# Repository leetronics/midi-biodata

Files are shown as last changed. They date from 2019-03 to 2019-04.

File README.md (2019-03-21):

# MIDI Biodata Sonification system

This repository was originally a fork of https://github.com/electricityforprogress/MIDIsprout, but is now maintained seperately by 13-37.org electronics.

Here you find the hardware and enclosure design files for the MIDI Biodata Sonification Devices produced by 13-37.org electronics.

- enclosures: contains FreeCAD design and STL files for the enclosure
- firmware: 
  - MIDI_Psychogalv_328p_v021: unmodified firmware from electricityforprogress/MIDIsprout
  - MIDI_Psychogalv_328p_13-37.org_v2.0: firmware for MIDI Biodata Sonification Device by 13-37.org electronics
- kicad: hardware design as KiCAD project and Gerber files

The hardware design and firmware is based on the work of electricityforprogress and thus licensed under the MIT license.

The enclosure design is however licensed under CC0 (public domain), except for the logo which is under copyright of [DipthDesign](https://www.dipth.de). For private use, anyone is free to print the enclosure with logo and without permission.

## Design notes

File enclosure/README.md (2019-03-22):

## Enclosure design files

All design files are made with FreeCAD (fcstd files). 
The provided STL files are not neccesarily up to date, but it's all compatible.

### Main body

This version is 5mm higher than the earlier revision, so it fits the classic MIDI Biodata Sonification devices,
even those with trough-hole LEDs or a protruding oscillator.

But I also recommend it for variants with flat LEDs (like newer devices from DataGarden or the the MIDI Biodata Sonification Device v2.1 by 13-37.org)
as it has better light diffusion with the increased distance.

### Main body

This version fits only the MIDI biodata Sonification Device v2.1 by 13-37.org, and is 5mm smaller(in height) than the version above.

    midi-biodata-case.fcstd
    midi-biodata-case-v10.stl

### Bottom Cover

    midi-biodata-lid.fcstd
    midi-biodata-lid.stl

### Light diffuser

Just a plate of 51,5mm x 48,75mm x 1mm. It snaps into the main body.

    midi-biodata-diffuser.fcstd
    midi-biodata-diffuser.stl

### Button

    midi-biodata-button-16x.stl
    midi-biodata-button-big.stl
    midi-biodata-button.fcstd

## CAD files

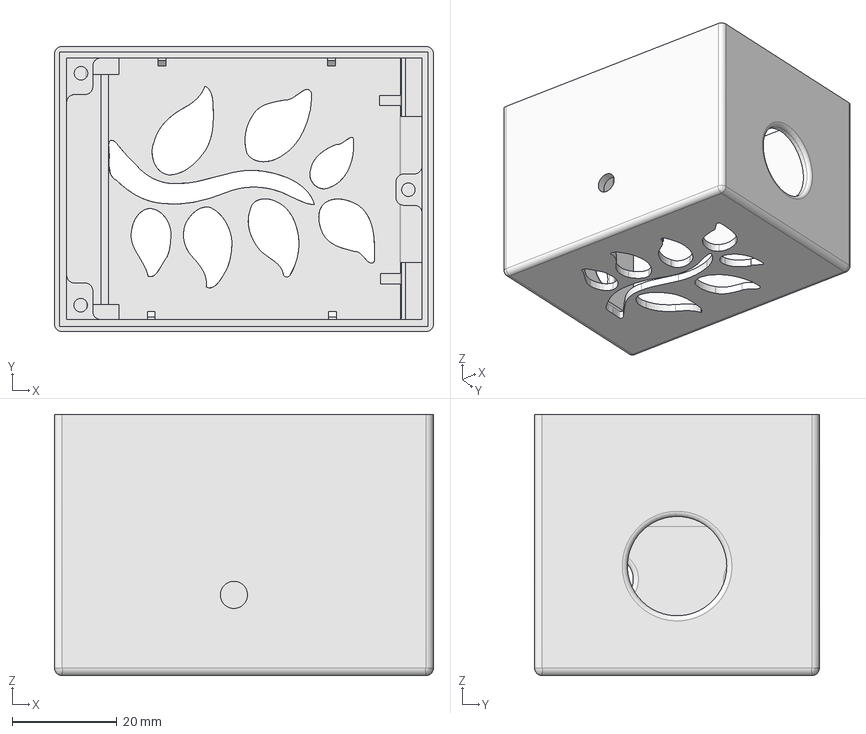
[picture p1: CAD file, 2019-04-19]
enclosure/midi-biodata-case.fcstd
72.5 x 54.5 x 50.0 mm

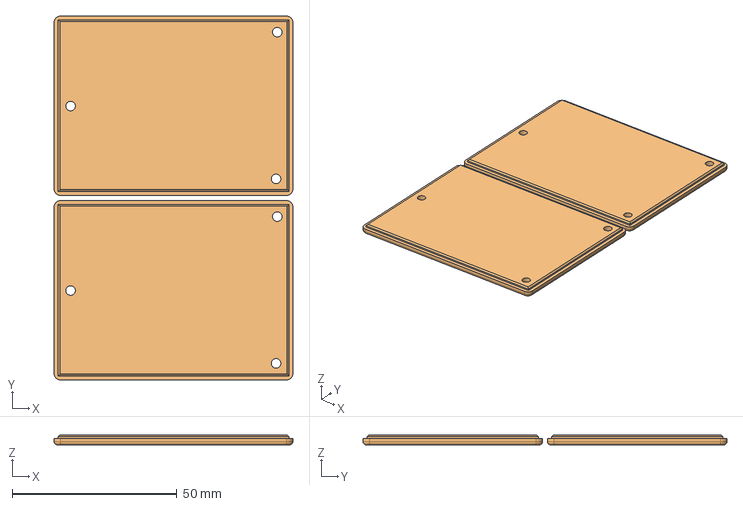
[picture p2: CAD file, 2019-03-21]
enclosure/midi-biodata-lid.fcstd
72.5 x 110.5 x 3.00 mm
Pocket003Body

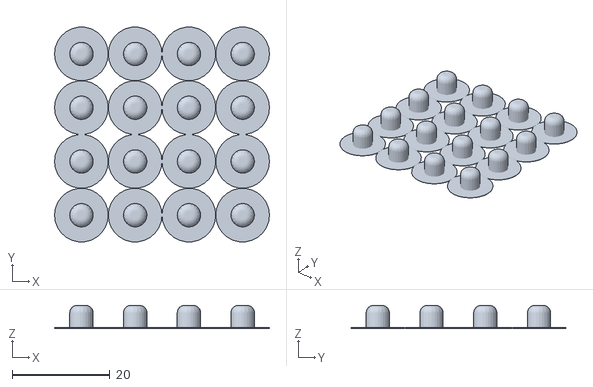
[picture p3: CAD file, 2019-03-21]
enclosure/midi-biodata-button-16x.stl
44.0 x 43.9 x 4.75

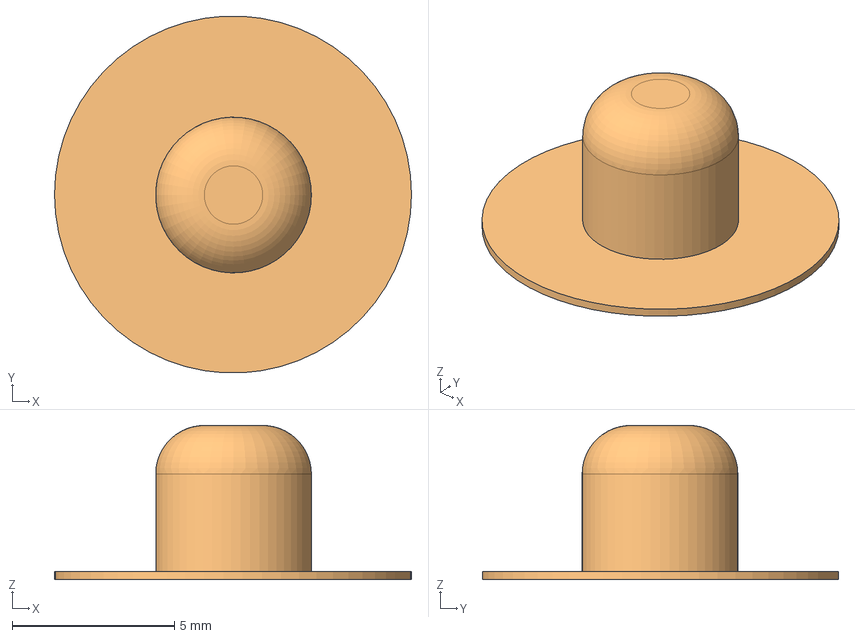
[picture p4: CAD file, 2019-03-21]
enclosure/midi-biodata-button.fcstd
11.0 x 11.0 x 4.75 mm

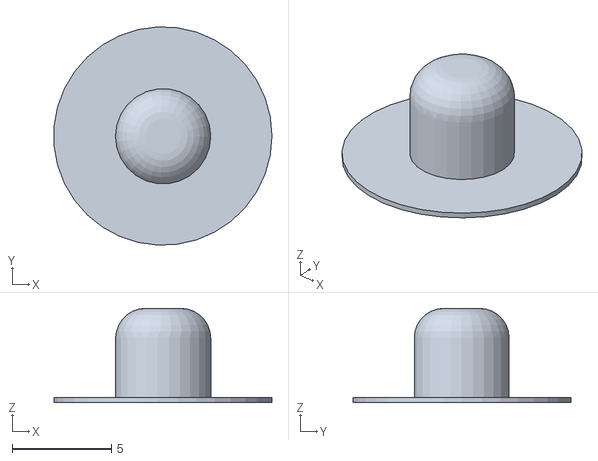
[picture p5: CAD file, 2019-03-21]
enclosure/midi-biodata-button-big.stl
11.0 x 11.0 x 4.75

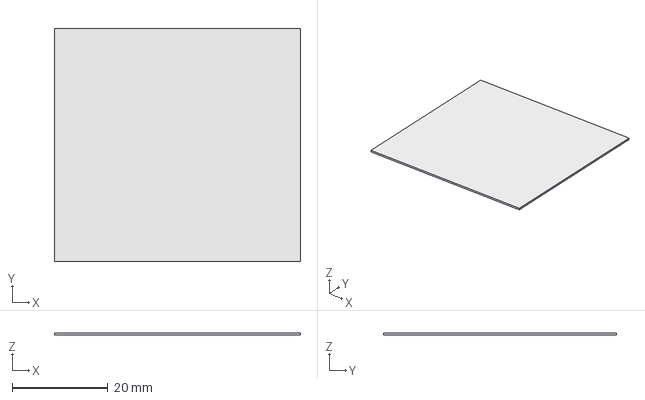
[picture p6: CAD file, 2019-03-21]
enclosure/midi-biodata-diffuser.fcstd
51.5 x 48.8 x 0.5 mm

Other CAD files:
enclosure/midi-biodata-case-v11.stl
enclosure/midi-biodata-case-v10.stl
enclosure/midi-biodata-diffuser.stl
enclosure/midi-biodata-lid.stl

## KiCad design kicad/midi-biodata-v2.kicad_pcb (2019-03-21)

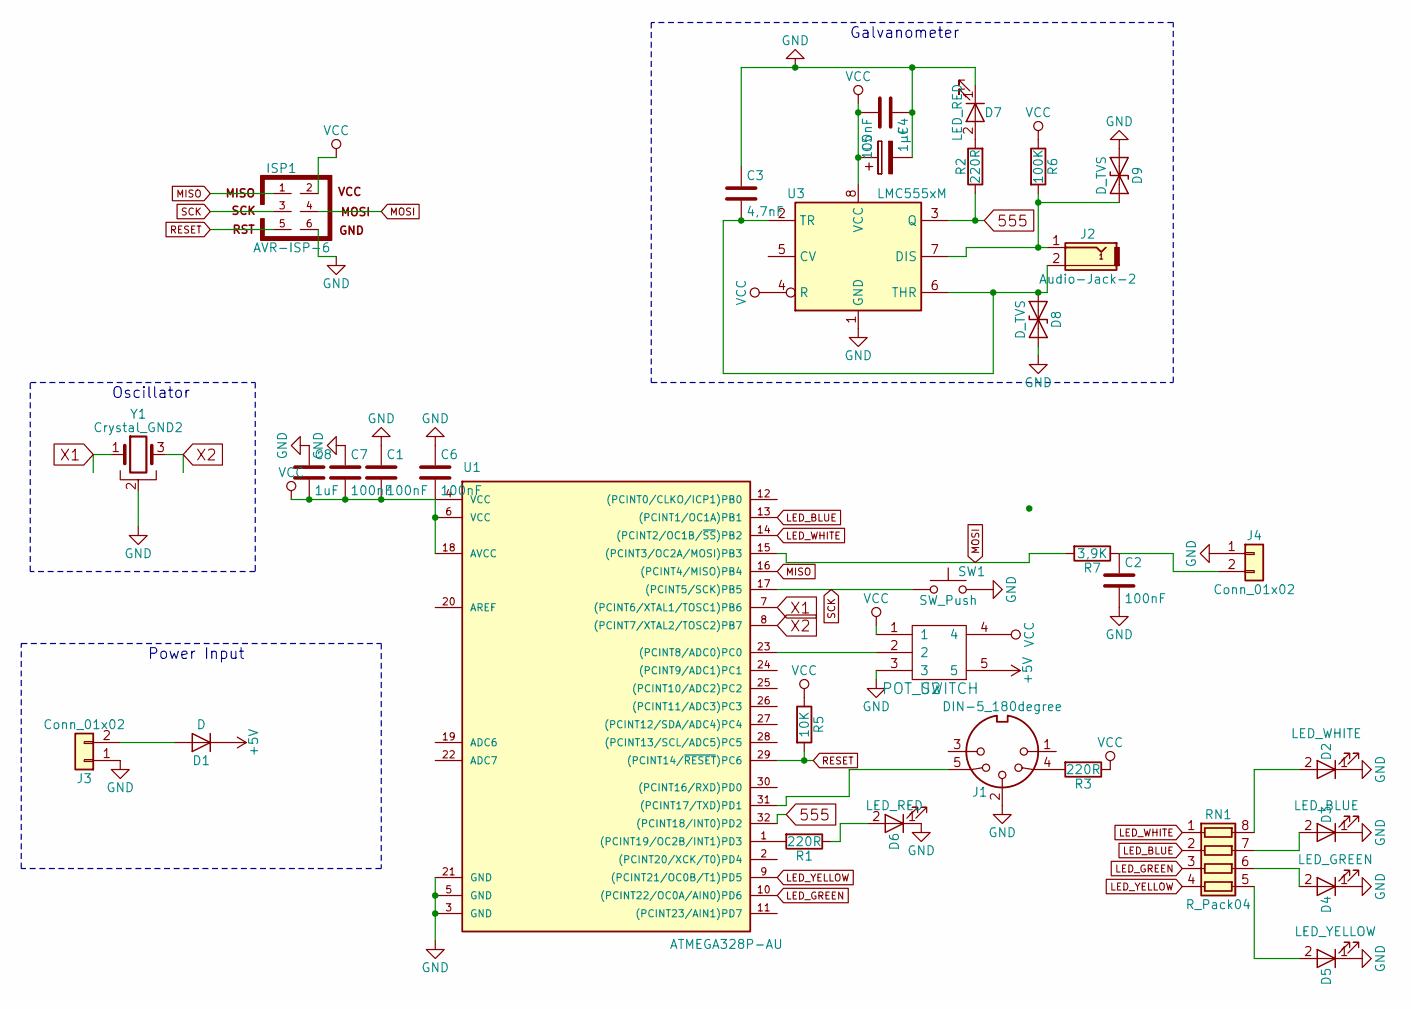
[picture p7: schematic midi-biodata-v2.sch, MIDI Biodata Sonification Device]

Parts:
C1, C2, C4: 100nF; C_1206
C3: 4,7nF; C_1206
C5: 1µF; CP_Radial_D5.0mm_P2.50mm
C6, C7: 100nF; C_0805
C8: 1uF; C_0805
D1: D; D_1206
D2: LED_WHITE; LED_1206_HandSoldering
D3: LED_BLUE; LED_1206_HandSoldering
D4: LED_GREEN; LED_1206_HandSoldering
D5: LED_YELLOW; LED_1206_HandSoldering
D6, D7: LED_RED; LED_1206_HandSoldering
D8, D9: D_TVS; D_0805
ISP1: AVR-ISP-6; Pin_Header_Straight_2x03_Pitch2.54mm
J1: DIN-5_180degree; DIN-5-MIDI-JACK
J2: Audio-Jack-2; mono-jack
J3, J4: Conn_01x02; Pin_Header_Straight_1x02_Pitch2.54mm
R1, R2, R3: 220R; R_1206
R5: 10K; R_0805
R6: 100K; R_1206
R7: 3,9K; R_1206
RN1: R_Pack04; R_Array_Concave_4x0603
SW1: SW_Push; SW_Tactile_SPST_Angled
U1: ATMEGA328P-AU; TQFP-32_7x7mm_Pitch0.8mm
U2: POT_SWITCH
U3: LMC555xM; DIP-8_W7.62mm
Y1: Crystal_GND2; murata-cstce

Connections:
555: R2.1, U1.32 ((PCINT18/INT0)PD2), U3.3 (Q)
+5V: D1.1 (K), U2.5
GND: C1.1, C2.2, C3.1, C4.1, C5.2, C6.1, C7.1, C8.1, D2.1 (K), D3.1 (K), D4.1 (K), D5.1 (K), D6.1 (K), D7.1 (K), D8.2 (A2), D9.1 (A1), ISP1.6, J1.2, J3.1, J4.1, SW1.2, U1.3 (GND), U1.5 (GND), U1.21 (GND), U2.3, U3.1 (GND), Y1.2
LED_BLUE: RN1.2 (R2.1), U1.13 ((PCINT1/OC1A)PB1)
LED_GREEN: RN1.3 (R3.1), U1.10 ((PCINT22/OC0A/AIN0)PD6)
LED_WHITE: RN1.1 (R1.1), U1.14 ((PCINT2/OC1B/~SS~)PB2)
LED_YELLOW: RN1.4 (R4.1), U1.9 ((PCINT21/OC0B/T1)PD5)
MISO: ISP1.1, U1.16 ((PCINT4/MISO)PB4)
MOSI: ISP1.4, R7.2, U1.15 ((PCINT3/OC2A/MOSI)PB3)
unnamed: C2.1, J4.2, R7.1
unnamed: C3.2, D8.1 (A1), J2.2, U3.2 (TR), U3.6 (THR)
unnamed: D1.2 (A), J3.2
unnamed: D2.2 (A), RN1.8 (R1.2)
unnamed: D3.2 (A), RN1.7 (R2.2)
unnamed: D4.2 (A), RN1.6 (R3.2)
unnamed: D5.2 (A), RN1.5 (R4.2)
unnamed: D6.2 (A), R1.1
unnamed: D7.2 (A), R2.2
unnamed: D9.2 (A2), J2.1, R6.2, U3.7 (DIS)
unnamed: J1.4, R3.2
unnamed: J1.5, U1.31 ((PCINT17/TXD)PD1)
unnamed: R1.2, U1.1 ((PCINT19/OC2B/INT1)PD3)
unnamed: U1.23 ((PCINT8/ADC0)PC0), U2.2
RESET: ISP1.5, R5.2, U1.29 ((PCINT14/~RESET~)PC6)
SCK: ISP1.3, SW1.1, U1.17 ((PCINT5/SCK)PB5)
VCC: C1.2, C4.2, C5.1, C6.2, C7.2, C8.2, ISP1.2, R3.1, R5.1, R6.1, U1.4 (VCC), U1.6 (VCC), U1.18 (AVCC), U2.1, U2.4, U3.4 (R), U3.8 (VCC)
X1: U1.7 ((PCINT6/XTAL1/TOSC1)PB6), Y1.1
X2: U1.8 ((PCINT7/XTAL2/TOSC2)PB7), Y1.3

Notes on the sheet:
Galvanometer
Oscillator
Power Input

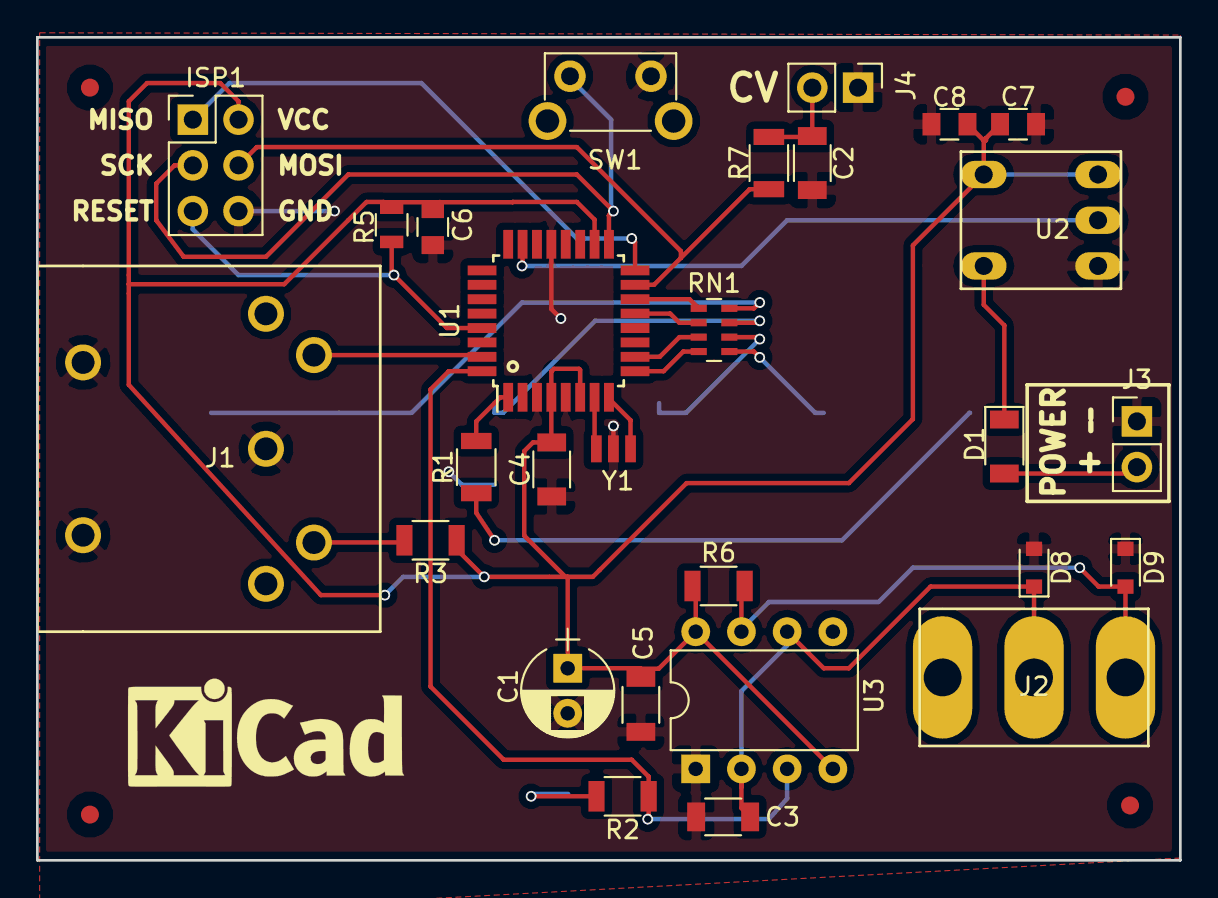
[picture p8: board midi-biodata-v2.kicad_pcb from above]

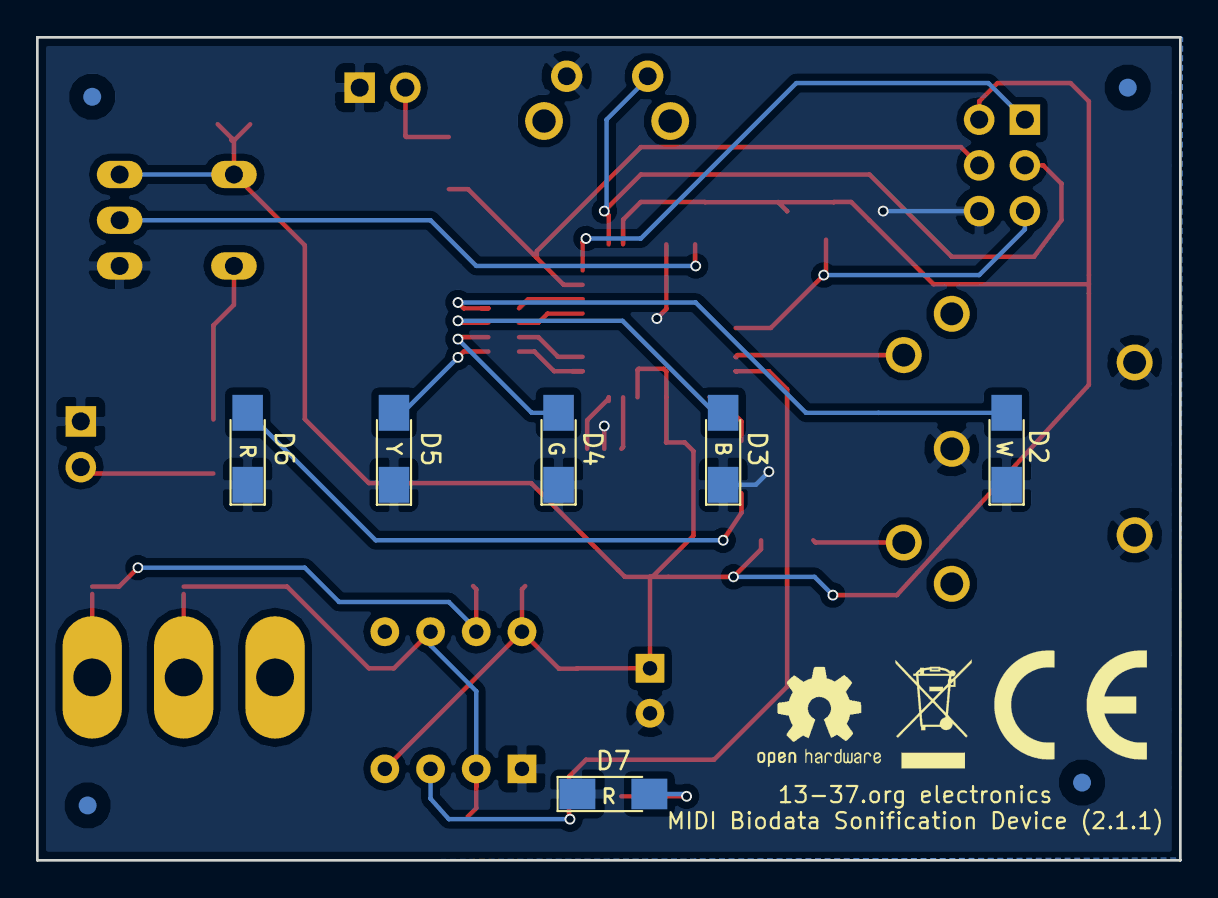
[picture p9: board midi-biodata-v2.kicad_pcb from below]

Board: 2 copper layers, 63.5 x 45.7 mm, 34 parts (6 on the bottom side), 28 nets.

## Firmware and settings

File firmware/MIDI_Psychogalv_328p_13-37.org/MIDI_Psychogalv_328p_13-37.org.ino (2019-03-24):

/*------------
  MIDI_PsychoGalvanometer v2.0
  Accepts pulse inputs from a Galvanic Conductance sensor
  consisting of a 555 timer set as an astablemultivibrator and two electrodes.
  Through sampling pulse widths and identifying fluctuations, MIDI note and control messages
  are generated.  Features include Threshold, Scaling, Control Number, and Control Voltage
  using PWM through an RC Low Pass filter.
  MIDIsprout.com

  modified by 13-37.org:
  - added EEPROM support and menu functionality from the Arduino shield version https://github.com/electricityforprogress/BiodataSonificationBreadboardKit
  -------------*/

#include <EEPROM.h>
#include <LEDFader.h> //manage LEDs without delay() jgillick/arduino-LEDFader https://github.com/jgillick/arduino-LEDFader.git

//#define DEBUG
#define SCHEMA 0x02
#define BUTTON_DEBOUNCE 100

//******************************
//set scaled values, sorted array, first element scale length
const int scaleCount = 4;
const int scaleLen = 13; //maximum scale length plus 1 for 'used length'

uint16_t currScale = 0; //current scale, default Chrom // SETTING
uint16_t maxBrightness = 190; // SETTING
uint16_t channel = 1;  //setting channel to 11 or 12 often helps simply computer midi routing setups // SETTING
float threshold = 2.3;   //2.3;  //change threshold multiplier // SETTING
float threshMin = 1.61; //scaling threshold min
float threshMax = 3.71; //scaling threshold max

int scale[scaleCount][scaleLen] = {
  {12, 1, 2, 3, 4, 5, 6, 7, 8, 9, 10, 11, 12}, //Chromatic
  {7, 1, 3, 5, 6, 8, 10, 12}, //Major
  {7, 1, 2, 2, 5, 6, 9, 11}, //Indian
  {7, 1, 3, 4, 6, 8, 9, 11} //Minor
};

int root = 0; //initialize for root, pitch shifting
//*******************************

const byte interruptPin = INT0; //galvanometer input
const byte knobPin = A0; //knob analog input
//Bounce button = Bounce(); //debounce button using Bounce2
const byte buttonPin = 13; //tact button input
int menus = 4; //number of main menus
int mode = 0; //0 = Threshold, 1 = Scale, 2 = Brightness, 3 = Channel
int currMenu = 0;
int pulseRate = 350; //base pulse rate

const byte samplesize = 10; //set sample array size
const byte analysize = samplesize - 1;  //trim for analysis array

const byte polyphony = 5; //above 8 notes may run out of ram

int noteMin = 36; //C2  - keyboard note minimum
int noteMax = 96; //C7  - keyboard note maximum
byte QY8 = 0; //sends each note out chan 1-4, for use with General MIDI like Yamaha QY8 sequencer
byte controlNumber = 80; //set to mappable control, low values may interfere with other soft synth controls!!
byte controlVoltage = 1; //output PWM CV on controlLED, pin 17, PB3, digital 11 *lowpass filter
long batteryLimit = 3000; //voltage check minimum, 3.0~2.7V under load; causes lightshow to turn off (save power)
byte checkBat = 1;

byte timeout = 0;
int value = 0;
int prevValue = 0;

volatile unsigned long microseconds; //sampling timer
volatile byte index = 0;
volatile unsigned long samples[samplesize];
float knobMin = 1;
float knobMax = 1024;

unsigned long previousMillis = 0;
unsigned long previousButtonMillis = 0;
unsigned long currentMillis = 1;

unsigned long batteryCheck = 5000; //battery check delay timer
unsigned long menuTimeout = 5000; //5 seconds timeout in menu mode

#define LED_NUM 6

LEDFader leds[LED_NUM] = { // 6 LEDs (perhaps 2 RGB LEDs)
  LEDFader(3),
  LEDFader(5),
  LEDFader(6),
  LEDFader(9),
  LEDFader(10),
  LEDFader(11)  //Control Voltage output or controlLED
};

int ledNums[LED_NUM] = {3, 5, 6, 9, 10, 11};
byte controlLED = 5; //array index of control LED (CV out)
byte noteLEDs = 1;  //performs lightshow set at noteOn event

typedef struct _MIDImessage { //build structure for Note and Control MIDImessages
  unsigned int type;
  int value;
  int velocity;
  long duration;
  long period;
  int channel;
}
MIDImessage;
MIDImessage noteArray[polyphony]; //manage MIDImessage data as an array with size polyphony
int noteIndex = 0;
MIDImessage controlMessage; //manage MIDImessage data for Control Message (CV out)

void setup()
{
  pinMode(knobPin, INPUT);
  pinMode(buttonPin, INPUT);
  pinMode(10, OUTPUT);
  digitalWrite(buttonPin, HIGH);
  readSettings();
  randomSeed(analogRead(0)); //seed for QY8 4 channel mode

#ifdef DEBUG
  cli();
  Serial.begin(9600); //for debugging
  Serial.println("MIDI_Sprout_V027+");
  sei();
#else
  Serial.begin(31250);  //initialize at MIDI rate
#endif
  controlMessage.value = 0;  //begin CV at 0
  //MIDIpanic(); //dont panic, unless you are sure it is nessisary
  checkBattery(); // shut off lightshow if power is too low
  if (noteLEDs) bootLightshow(); //a light show to display on system boot
  attachInterrupt(interruptPin, sample, RISING);  //begin sampling from interrupt
  pciSetup(buttonPin);
}

//interrupt timing sample array
void sample()
{
  //cli();
  if (index < samplesize) {
    samples[index] = micros() - microseconds;
    //micros() is very slow
    //try a higher precision counter:
    //samples[index] = ((timer0_overflow_count << 8) + TCNT0) - microseconds;
    microseconds = samples[index] + microseconds; //rebuild micros() value w/o recalling
    index += 1;
  }
  //sei();
}

long buttonPressed = 0;

void loop()
{
  currentMillis = millis();   //manage time
  checkBattery(); //on low power, shutoff lightShow, continue MIDI operation

  if (index >= samplesize)  {
    analyzeSample();  //if samples array full, also checked in analyzeSample(), call sample analysis
  }

  checkNote();  //turn off expired notes
  checkControl();  //update control value
  checkLED();  //LED management without delay()

  if ((currentMillis - buttonPressed ) < 100) {
    checkButton();
  }

  if (currMenu > 0) {
    checkMenu(); //allow main loop by checking current menu mode, and updating millis
  }
}


void checkButton() {
  if (digitalRead(buttonPin) == LOW) {
    delay(BUTTON_DEBOUNCE);
    if (digitalRead(buttonPin) == LOW) {
      noteLEDs = 0; //turn off normal light show for menu modes
      for (byte j = 0; j < LED_NUM; j++) {
        leds[j].stop_fade();  //off LEDs
        leds[j].set_value(0);
      }
      delay(250);
      switch (currMenu) {
        case 0: //this is the main sprout program
          prevValue = 0;
          currMenu = 1;
          previousMillis = currentMillis;
          break;
        case 1: //this is the main selection menu
          //value is menu selected
          switch (value) {
            case 0:
              delay(250);
              thresholdMode(); //set change threshold multiplier
              return;
              break;
            case 1:
              delay(250);
              scaleMode(); //set note scale
              return;
              break;
            case 2:
              delay(250);
              channelMode(); //set MIDI output channel
              return;
              break;
            case 3:
              brightnessMode(); //set LED max brightness
              return;
              break;
            default:
              break;
          }
          break;
        default:
          break;
      }
    }
  }
}

ISR (PCINT0_vect) {
  if (digitalRead(buttonPin) == LOW) {
    buttonPressed = millis();
  }
}

void pciSetup(byte pin)
{
  *digitalPinToPCMSK(pin) |= bit (digitalPinToPCMSKbit(pin));  // enable pin
  PCIFR  |= bit (digitalPinToPCICRbit(pin)); // clear any outstanding interrupt
  PCICR  |= bit (digitalPinToPCICRbit(pin)); // enable interrupt for the group
}

void readSettings() {
  // check if eeprom is emtpy or not
  short schema;
  EEPROM_readAnything(0, schema);
  if (schema != SCHEMA) {
    initializeEEPROM();
  }

  // check if MENU button is hold down for > 1s (to reset EEPROM settings)
  if (digitalRead(buttonPin) == LOW) {
    delay(1000);
    if (digitalRead(buttonPin) == LOW) {
      initializeEEPROM();
    }
    // blink WHITE LED 3 times (500ms)
    blinkLED(3, 500);
  }

  // read!
  EEPROM_readAnything(1, currScale);
  EEPROM_readAnything(3, maxBrightness);
  EEPROM_readAnything(5, channel);
  EEPROM_readAnything(7, threshold);
}

void initializeEEPROM() {
  EEPROM_writeAnything(1, 0); // curScale default value
  EEPROM_writeAnything(3, 255); // maxBrightness default value
  EEPROM_writeAnything(5, 1); // MIDI channel default value
  EEPROM_writeAnything(7, 2.3f); // threshold default value
  EEPROM_writeAnything(0, SCHEMA);
}


void blinkLED(int num, int milis) {
  for (int i = 0; i < num; i++) {
    digitalWrite(10, HIGH);
    delay(milis);
    digitalWrite(10, LOW);
    if (i != num - 1) {
      delay(milis);
    }
  }
}

template <class T> int EEPROM_writeAnything(int ee, const T& value)
{
  const byte* p = (const byte*)(const void*)&value;
  unsigned int i;
  for (i = 0; i < sizeof(value); i++)
    EEPROM.write(ee++, *p++);
  return i;
}

template <class T> int EEPROM_readAnything(int ee, T& value)
{
  byte* p = (byte*)(void*)&value;
  unsigned int i;
  for (i = 0; i < sizeof(value); i++)
    *p++ = EEPROM.read(ee++);
  return i;
}

void setNote(int value, int velocity, long duration, int notechannel) {
  //find available note in array (velocity = 0);
  for (int i = 0; i < polyphony; i++) {
    if (!noteArray[i].velocity) {
      //if velocity is 0, replace note in array
      noteArray[i].type = 0;
      noteArray[i].value = value;
      noteArray[i].velocity = velocity;
      noteArray[i].duration = currentMillis + duration;
      noteArray[i].channel = notechannel;

      if (QY8) {
        midiSerial(144, notechannel, value, velocity);
      }
      else {
        midiSerial(144, channel, value, velocity);
      }

      if (noteLEDs == 1) { //normal mode
        for (byte j = 0; j < (LED_NUM - 1); j++) { //find available LED and set
          if (!leds[j].is_fading()) {
            rampUp(i, maxBrightness, duration);
            break;
          }
        }
      } else if (noteLEDs == 2) { //threshold special display mode
        for (byte j = 1; j < (LED_NUM - 1); j++) { //find available LED above first and set
          if (!leds[j].is_fading()) {
            rampUp(i, maxBrightness, duration);
            break;
          }
        }
      }

      break;
    }
  }
}

void setControl(int type, int value, int velocity, long duration)
{
  controlMessage.type = type;
  controlMessage.value = value;
  controlMessage.velocity = velocity;
  controlMessage.period = duration;
  controlMessage.duration = currentMillis + duration; //schedule for update cycle
}


void checkControl()
{
  //need to make this a smooth slide transition, using high precision
  //distance is current minus goal
  signed int distance =  controlMessage.velocity - controlMessage.value;
  //if still sliding
  if (distance != 0) {
    //check timing
    if (currentMillis > controlMessage.duration) { //and duration expired
      controlMessage.duration = currentMillis + controlMessage.period; //extend duration
      //update value
      if (distance > 0) {
        controlMessage.value += 1;
      } else {
        controlMessage.value -= 1;
      }

      //send MIDI control message after ramp duration expires, on each increment
      midiSerial(176, channel, controlMessage.type, controlMessage.value);

      //send out control voltage message on pin 17, PB3, digital 11
      if (controlVoltage) {
        if (distance > 0) {
          rampUp(controlLED, map(controlMessage.value, 0, 127, 0 , 255), 5);
        }
        else {
          rampDown(controlLED, map(controlMessage.value, 0, 127, 0 , 255), 5);
        }
      }
    }
  }
}

void checkNote()
{
  for (int i = 0; i < polyphony; i++) {
    if (noteArray[i].velocity) {
      if (noteArray[i].duration <= currentMillis) {
        //send noteOff for all notes with expired duration
        if (QY8) {
          midiSerial(144, noteArray[i].channel, noteArray[i].value, 0);
        }
        else {
          midiSerial(144, channel, noteArray[i].value, 0);
        }
        noteArray[i].velocity = 0;
        if (noteLEDs == 1) rampDown(i, 0, 225);
        if (noteLEDs == 2) rampDown(i + 1, 0, 225); //special threshold display mode
      }
    }
  }
}

void MIDIpanic()
{
  //120 - all sound off
  //123 - All Notes off
  // midiSerial(21, panicChannel, 123, 0); //123 kill all notes

  //brute force all notes Off
  for (byte i = 1; i < 128; i++) {
    delay(1); //don't choke on note offs!
    midiSerial(144, channel, i, 0); //clear notes on main channel

    if (QY8) { //clear on all four channels
      for (byte k = 1; k < 5; k++) {
        delay(1); //don't choke on note offs!
        midiSerial(144, k, i, 0);
      }
    }
  }


}

void midiSerial(int type, int channel, int data1, int data2) {
  cli(); //kill interrupts, probably unnessisary
  //  Note type = 144
  //  Control type = 176
  // remove MSBs on data
  data1 &= 0x7F;  //number
  data2 &= 0x7F;  //velocity
  // commented out to make channel adjustment work - needs more testing

  byte statusbyte = (type | ((channel - 1) & 0x0F));

#ifdef DEBUG
  //Serial.println(statusbyte);
  if (type == 144) {
    Serial.println(data1);
  }
  //Serial.println(data2);
  //Serial.println();
#else
  Serial.write(statusbyte);
  Serial.write(data1);
  Serial.write(data2);
#endif
  sei(); //enable interrupts
}

void knobMode() {
  //scroll through menus and select values using only a single knob
  //keep dreamin' kid,
}

void rampUp(int ledPin, int value, int time) {
  LEDFader *led = &leds[ledPin];
  //scale the value parameter against a new maxBrightness global variable
  //  led->fade(value, time);
  led->fade(map(value, 0, 255, 0, maxBrightness), time);
}

void rampDown(int ledPin, int value, int time) {
  LEDFader *led = &leds[ledPin];
  // led->set_value(255); //turn on
  led->fade(value, time); //fade out
}

void checkLED() {
  //iterate through LED array and call update
  for (byte i = 0; i < LED_NUM; i++) {
    LEDFader *led = &leds[i];
    led->update();
  }
}

int checkButtonToExitMenu() {
  //if (bitRead(PINB, 5) == LOW) {
  if (digitalRead(buttonPin) == LOW) {
    delay(BUTTON_DEBOUNCE);
    //if (bitRead(PINB, 5) == LOW) {
    if (digitalRead(buttonPin) == LOW) {
      return 0;
    }
  }
  return 1;
}

void checkMenu() {
  //read the knob value, update LEDs, and wait for button press
  value = analogRead(knobPin);

  //scale knob value against number of menus
  value = map(value, knobMin, knobMax, 0, menus); //value is now menu index

  //set LEDs to flash based on value
  if (value != prevValue) { //a change in value
    //clear out prevValue LED
    leds[prevValue].stop_fade();
    leds[prevValue].set_value(0);
    prevValue = value; //store value
    previousMillis = currentMillis; //reset timeout
  }
  else { //no value change
  }
  switch (currMenu) {
    case 0:
      //this is the main sprout program
      break;
    case 1: //this is the main selection menu
      noteLEDs = 0;
      pulse(value, maxBrightness, pulseRate); //pulse for current menu
      break;
    case 2:  //this is the submenu
      noteLEDs = 0;
      pulse(value, maxBrightness, (pulseRate / 2)); //pulse for current menu
      break;

    default:
      break;
  }

  if ((currentMillis - previousMillis) > menuTimeout) { //menu timeout!!
    currMenu = 0; //return to main program exit all menus
    if (maxBrightness > 1) noteLEDs = 1; //normal light show, or leave off
    leds[prevValue].stop_fade();
    leds[prevValue].set_value(0);
  }

}


long readVcc() {  //https://code.google.com/p/tinkerit/wiki/SecretVoltmeter
  long result;
  // Read 1.1V reference against AVcc
  ADMUX = _BV(REFS0) | _BV(MUX3) | _BV(MUX2) | _BV(MUX1);
  delay(2); // Wait for Vref to settle
  ADCSRA |= _BV(ADSC); // Convert
  while (bit_is_set(ADCSRA, ADSC));
  result = ADCL;
  result |= ADCH << 8;
  result = 1126400L / result; // Back-calculate AVcc in mV
  return result;
}

void checkBattery() {
  //check battery voltage against internal 1.1v reference
  //if below the minimum value, turn off the light show to save power
  //don't check on every loop, settle delay in readVcc() slows things down a bit
  if (batteryCheck < currentMillis) {
    batteryCheck = currentMillis + 10000; //reset for next battery check

    if (readVcc() < batteryLimit) {  //if voltage > valueV
      //battery failure
      if (checkBat) { //first battery failure
        for (byte j = 0; j < LED_NUM; j++) {
          leds[j].stop_fade();  //reset leds, power savings
          leds[j].set_value(0);
        }
        noteLEDs = 0;  //shut off lightshow set at noteOn event, power savings
        checkBat = 0; //update, first battery failure identified
      } else { //not first low battery cycle
        //do nothing, lights off indicates low battery
        //MIDI continues to flow, MIDI data eventually garbles at very low voltages
        //some USB-MIDI interfaces may crash due to garbled data
      }
    }
  }
}

void pulse(int ledPin, int maxValue, int time) {
  LEDFader *led = &leds[ledPin];
  //check on the state of the LED and force it to pulse
  if (led->is_fading() == false) { //if not fading
    if (led->get_value() > 0) { //and is illuminated
      led->fade(0, time); //fade down
    } else led->fade(maxValue, time); //fade up
  }
}

void bootLightshow() {
  //light show to be displayed on boot
  for (byte i = 5; i > 0; i--) {
    LEDFader *led = &leds[i - 1];
    //    led->set_value(200); //set to max

    led->fade(200, 150); //fade up
    while (led->is_fading()) checkLED();

    led->fade(0, 150 + i * 17); //fade down
    while (led->is_fading()) checkLED();
    //move to next LED
  }
}


//provide float map function
float mapfloat(float x, float in_min, float in_max, float out_min, float out_max)
{
  return (x - in_min) * (out_max - out_min) / (in_max - in_min) + out_min;
}


void thresholdMode() {
  int runMode = 1;
  noteLEDs = 2; //turn on special Note visualization for feedback on threshold effect
  while (runMode) {
    //float knobValue
    threshold = analogRead(knobPin);
    //set threshold to knobValue mapping
    threshold = mapfloat(threshold, knobMin, knobMax, threshMin, threshMax);
    pulse(value, maxBrightness, (pulseRate / 2)); //pulse for current menu

    checkLED();
    if (index >= samplesize)  {
      analyzeSample();  //keep samples running
    }
    checkNote();  //turn off expired notes
    checkControl();  //update control value

    runMode = checkButtonToExitMenu();

    currentMillis = millis();
  }
  EEPROM_writeAnything(7, threshold); // threshold default value

  currMenu = 0; //return to main program
  noteLEDs = 1; //normal light show
  leds[prevValue].stop_fade();
  leds[prevValue].set_value(0);
}


void scaleMode() {
  int runMode = 1;
  int prevScale = 0;
  while (runMode) {
    currScale = analogRead(knobPin);
    //set current Scale choice
    currScale = map(currScale, knobMin, knobMax, 0, scaleCount);

    pulse(value, maxBrightness, (pulseRate / 2)); //pulse for current menu
    pulse(currScale, maxBrightness, (pulseRate / 4)); //display selected scale if scaleCount <= 5

    if (currScale != prevScale) { //clear last value if change
      leds[prevScale].stop_fade();
      leds[prevScale].set_value(0);
    }
    prevScale = currScale;

    checkLED();
    if (index >= samplesize)  {
      analyzeSample();  //keep samples running
    }
    checkNote();  //turn off expired notes
    checkControl();  //update control value

    runMode = checkButtonToExitMenu();
  }  //after button press retain threshold setting
  EEPROM_writeAnything(1, currScale); // curScale default value
  noteLEDs = 1; //normal light show
  leds[prevValue].stop_fade();
  leds[prevValue].set_value(0);
  leds[currScale].stop_fade();
  leds[currScale].set_value(0);
}

void displayChannel(int channel) {
   // update LEDs to indicate current channel (with 5-bit using the LEDs: R-Y-G-B-W/1-2-4-8-16)
   for (byte i = 0; i < 5; i++) {
        digitalWrite(ledNums[i], channel & 1);
        channel /= 2;
      }
}

void channelMode() {
  int runMode = 1;
  int prevChannel = channel;
  while (runMode) {
    channel = analogRead(knobPin);
    //set current MIDI Channel between 1 and 16
    if (prevChannel != channel) {
      channel = map(channel, knobMin, knobMax, 1, 17);
      displayChannel(channel);
    }
    if (index >= samplesize)  {
      analyzeSample();  //keep samples running
    }
    checkNote();  //turn off expired notes
    checkControl();  //update control value
    runMode = checkButtonToExitMenu();
  }  //after button press retain channel setting
  EEPROM_writeAnything(5, channel); // MIDI channel default value
  currMenu = 0; //return to main program
  noteLEDs = 1; //normal light show
  for (int i =0; i<5;i++) {
    digitalWrite(ledNums[i], LOW);
  }
}

void brightnessMode() {
  int runMode = 1;
  while (runMode) {

    maxBrightness = analogRead(knobPin);
    //set led maxBrightness
    maxBrightness = map(maxBrightness, knobMin, knobMax, 1, 255);

    if (maxBrightness > 1) pulse(value, maxBrightness, (pulseRate / 2)); //pulse for current menu
    else pulse(value, 1, (pulseRate / 6)); //fast dim pulse for 0 note lightshow

    checkLED();
    if (index >= samplesize)  {
      analyzeSample();  //keep samples running
    }
    checkNote();  //turn off expired notes
    checkControl();  //update control value

    runMode = checkButtonToExitMenu();
    currentMillis = millis();
  }  //after button press retain threshold setting
  EEPROM_writeAnything(3, maxBrightness);
  currMenu = 0; //return to main program
  if (maxBrightness > 1) noteLEDs = 1; //normal light show, unles lowest value
  leds[prevValue].stop_fade();
  leds[prevValue].set_value(0);
}
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

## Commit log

2019-03-21 upload midi biodata source files
    [midi-biodata-v2-bom.ods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]
2019-03-21 upload v2.1
    [midi-biodata-v2-B.Cu.gbl, midi-biodata-v2-B.Cu.gbr, midi-biodata-v2-B.Mask.gbr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]
2019-03-22 updated enclosure design files
    [midi-biodata-button-16x.stl, midi-biodata-button-big.stl, midi-biodata-button.fcstd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]
2019-03-22 increased button hole and flipped logo
    [midi-biodata-case-v10.stl, midi-biodata-case.fcstd]
2019-03-22 move button position
    [midi-biodata-case-v10.stl, midi-biodata-case.fcstd]
2019-03-22 add some clearance
    [midi-biodata-case-v10.stl, midi-biodata-case.fcstd]
2019-03-24 configure MIDI channel with visual feedback (binary encoded using 5 LEDs)
2019-04-19 increase hole diameter for MIDI connector
    [midi-biodata-case-v11.stl, midi-biodata-case.fcstd]
